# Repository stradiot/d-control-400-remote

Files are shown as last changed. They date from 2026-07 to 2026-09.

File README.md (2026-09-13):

# Dogtrace d-control 400 remote clone (ESP32-C3 + CC1101)

A small ESP32-C3 board that reproduces the *beep* command of a Dogtrace d-control 400 dog collar, making it triggerable from Home Assistant rather than only from the handheld remote.

The repository contains everything needed to build one: firmware for two runtimes (bare PlatformIO, and ESPHome for the Home Assistant path), a fabrication-ready PCB, a 3D printable enclosure, the SDR analysis script, and a written account of how the radio link was measured and decoded.

⚠️ **Scope and disclaimers**

* **Undocumented protocol.** Dogtrace publishes nothing about the link. Everything here was measured from SDR captures. The frame has since been decoded far enough to describe its structure — see [What the frame looks like](#-what-the-frame-looks-like) — but the firmware **does not use that decode**. It still replays a stored payload verbatim.
* **Raw replay, not synthesis.** The transmitted signal is a fixed-code payload captured with an SDR, cleaned up and re-emitted as raw timings, clocked onto the CC1101's GDO0 pin by the ESP32-C3's RMT peripheral in asynchronous direct mode: no packet engine, no sync word, no CRC. The encoding is **run-length** — all the information is in the durations and none in the levels. It is *not* PWM, despite what earlier revisions of this file claimed: PWM would need exactly half the runs long, and a real frame has 21 long runs out of 88.
* **Device specific.** The payload committed here was captured from one physical remote and is not a universal key for every d-control 400. The 68 runs that stay constant across everything that handset can send are *assumed* to be its identity — an assumption that has never been tested, because testing it needs a second remote. See [What the frame looks like](#-what-the-frame-looks-like). What this repository gives you is a structural template; you supply your own captured frame.
* **A fresh clone does not compile.** `include/signal.h` in this repository is encrypted, so it is not valid C. Replace it with your own capture using the template in [Providing your own signal](#-providing-your-own-signal).
* **Beep only.** The shock function is deliberately out of scope. As of the September 2026 decode that is a policy rather than a limitation: the frame is understood well enough to construct a shock command, and this repository deliberately does not carry what would be required to build one.
* **Legal.** 868 MHz is a licence-exempt band in Europe with duty-cycle limits, and transmitting on it is your responsibility. So is anything you do with a device that talks to an animal's collar.

---

## 📺 Demo

Demonstration of the project triggering the collar's sound beep function.

<div align="center">
  <video src="https://github.com/user-attachments/assets/95b2df5f-6e3d-44ce-ad21-af88bca1a0c2" controls="controls" style="max-width: 100%;">
  </video>
</div>

> **Note:** The video contains sound

---

## 📁 Repository Structure

```
.
├── src/main.cpp          # Standalone firmware — button, LED, TX sequence, serial console
├── include/              # Shared by the two firmware paths
│   ├── pinout.h          # Pin map for the custom SPI routing on the C3
│   ├── signal.h          # RF parameters + captured payload — ENCRYPTED, see below
│   ├── rmt_beep.h        # Transmission core — packs the frame, drives the RMT channel
│   ├── cc1101_config.h   # The six RadioLib calls that set the radio's RF personality
│   ├── led_policy.h      # Status LED palette, as levels emitted by the WS2812
│   └── reset_reason.h    # esp_reset_reason() as a printable string
├── esphome/              # Home Assistant path: d-control-400.yaml + cc1101.h
├── tools/analyze_capture.py  # IQ → envelope → run lengths → symbol period → frame → encoding tests
├── signal_captures.txt   # Decoded-frame worksheet — ENCRYPTED, not a build input
├── pcb/
│   ├── gerber.zip        # Fabrication-ready Gerbers
│   └── board-outline.dxf # Board outline, holes and pads in mm — for enclosure CAD
├── enclosure/            # Fusion 360 source + STEP + STL/3MF
├── doc/                  # Demo video, enclosure photos, PCB layer views
├── .githooks/            # Commit guard that keeps the two encrypted files encrypted
├── platformio.ini        # PlatformIO project/build configuration
└── README.md
```

`test/`, `lib/` and `include/README` are empty PlatformIO scaffolding. There are no tests.

The two encrypted files are the author's own captured data and are explained in [Encrypted files](#-encrypted-files-and-the-commit-guard). Nothing in the build reads `signal_captures.txt`.

---

## 🧰 Hardware Requirements

* **Microcontroller:** Wemos LOLIN C3 Mini (ESP32-C3, single-core RISC-V, USB-C).
* **Radio:** CC1101 transceiver module — must be the **868 MHz** variant with a **26 MHz** crystal. The 433 MHz part will not reach 869.525 MHz.
* **Antenna:** 868 MHz quarter-wave, roughly 8.2 cm.
* Optional: the PCB in `pcb/` and the printed enclosure in `enclosure/`. Hand-wiring on perfboard works just as well.

---

## 🔌 Wiring Diagram

The project uses a custom SPI bus routed to specific pins on the ESP32-C3. The physical BOOT button on GPIO 9 is used to trigger the transmission.

```mermaid
graph LR
    subgraph Wemos LOLIN C3 Mini
        3V3[3.3V Power]
        GND[Ground]
        G3[GPIO 3]
        G1[GPIO 1]
        G0[GPIO 0]
        G8[GPIO 8]
        G10[GPIO 10]
        G9[GPIO 9]
        G7[GPIO 7]
    end

    subgraph CC1101 Module
        VCC_C[VCC]
        GND_C[GND]
        MOSI[MOSI]
        SCK[SCK]
        MISO[MISO]
        GDO0[GDO0]
        CSN[CSN]
    end

    3V3 ---|Power| VCC_C
    GND ---|Ground| GND_C
    G3 ---|SPI MOSI| MOSI
    G1 ---|SPI SCK| SCK
    G0 ---|SPI MISO| MISO
    G8 ---|GDO0| GDO0
    G10 ---|SPI CS| CSN
    G9 ---|BOOT Button| BUTTON_PIN
    G7 ---|RGB LED| LED_PIN
```

Only **GDO0** is wired. Asynchronous direct mode maps that pin's logic level straight onto the power amplifier, so it is the entire data path; GDO2 is left unconnected.

---

## 🧩 PCB

A fabrication-ready two-layer board is included at `pcb/gerber.zip`. It routes the SPI bus and control pins between the LOLIN C3 Mini and the CC1101 module exactly as shown above. Upload the zip to any fab house (JLCPCB, PCBWay, OSH Park) as-is. It is optional — hand-wiring per the diagram is a fully valid alternative.

| Top | Bottom |
| :---: | :---: |
| PCB top layer | PCB bottom layer |

The dark rectangle sitting under the C3's antenna is the pour keepout, and it is visible on both views because it is cut through both layers. The bottom view is mirrored, as seen through the board.

`pcb/board-outline.dxf` carries the same geometry in millimetres — board outline, every drilled hole (24 plated, 4 mounting), pad positions and the module footprints, each on its own DXF layer. It is there so the mechanical side can be worked without opening an EDA tool: import it as a sketch in Fusion 360, FreeCAD or anything else that reads DXF, and build a case, a mounting plate or a panel cutout straight off the real dimensions.

**Layout**

* **Module placement.** The two modules sit at opposite ends of the board. The CC1101 is positioned so its antenna overhangs the board edge completely, with no substrate underneath to detune or absorb it. The C3 Mini is at the other end with its USB-C connector overhanging that edge, where the enclosure cutout reaches it — but its own antenna cannot be given the same treatment, because it falls close to the centre of the board, over laminate and copper pour. That is what the keepout below is for.
* **ESP antenna keepout.** A copper-pour keepout sits under the ESP32-C3's onboard antenna on **both** layers, so the antenna radiates through bare laminate rather than over a ground plane. It is a rectangle roughly 12 mm wide that extends about 3 mm past the end of the module, so the fringing field clears the pour as well as the antenna trace itself.
* **Mounting holes.** 2.032 mm at the corners, with the pour pulled back for clearance around the hardware.
* **Radio footprint.** The CC1101 header is 1×8 on a 2.00 mm pitch (`header-pin-1x8-2.00`), verified against the module.

**Routing**

* Power traces from the 3.3 V rail are 0.5 mm; signal traces are 0.254 mm.
* Ground pins tie into a full-coverage polygon pour through thermal reliefs, so the ground is solid but the pads still take a hand-soldering iron.
* DRC minimum track width was tuned to the design and the board passes cleanly.

**Ordering**

Fab defaults are fine for everything except board thickness: order **1.6 mm**, which is what the enclosure's standoffs are dimensioned for. The 0.5 mm power trace assumes 1 oz copper. Everything else — material, surface finish, mask colour — is free choice; the photographed board is black with leaded HASL because it was hand-assembled with leaded solder.

---

## 📡 CC1101 RF Configuration Summary

Only the carrier frequency comes from a datasheet. The rest were derived from SDR measurement and iterative testing against the collar.

| Parameter | Value | Why it matters |
| :--- | :--- | :--- |
| Carrier frequency | 869.525 MHz | The frequency the collar listens on. Confirmed on an SDR waterfall. |
| Output power | 10 dBm | Enough for whole-house range; see the note on chopping at range below. |
| Modulation | OOK | Confirmed on the waterfall — the carrier is simply gated on and off. |
| Bit rate | 100.0 kbps | Deliberate ~20× oversampling of a ~4.8 kBaud signal. Not a mistake — see below. |
| Rx bandwidth | 116.0 kHz | Selects a stable hardware filter tap off the 26 MHz crystal, on a transmit-only device. Not dead config. |
| Sync word | Disabled | Raw pulses; the packet engine is bypassed entirely. |
| Preamble / CRC | Disabled | Same reason — asynchronous direct mode. |
| Transmission mode | Asynchronous direct | GDO0's logic level maps straight to the PA. HIGH = RF on, LOW = RF off. |
| Symbol period | 208.647 µs | Measured, not estimated. Stored as 78 RMT channel ticks of 2.675 µs = 208.65 µs, +14 ppm. Every run is one or two of these. See [Measuring the symbol period](#measuring-the-symbol-period). |

---

## 🚀 Technical Specifics

### 1. 20× bitrate oversampling

A symbol period of 208.647 µs is a signalling rate of about 4.8 kBaud, yet the CC1101's data rate register is set to 100 kbps.

That is deliberate. In asynchronous mode the CC1101 samples the GDO0 pin on its own internal clock derived from that register. Set to 4.8 kbps it would look at the pin roughly once per symbol, and every edge would land wherever the two clocks happened to be relative to each other — visible as heavy jitter on the gating of the power amplifier. At 100 kbps it samples about every 10 µs, roughly 20 times per symbol, so each edge is reproduced to within a twentieth of a symbol. Do not "fix" this to match the real baud rate.

### 2. Receive bandwidth on a transmit-only device

`RX_BANDWIDTH` looks like dead configuration, and it is not. The CC1101 derives its channel filter from a chain of dividers off the 26 MHz crystal, and the register selects which tap. 116.0 kHz picks a tap that divides cleanly, which keeps the internal clock tree — and therefore the shape of the transmitted bursts — stable. In OOK the synthesiser stays parked at 869.525 MHz regardless.

### 3. Clocking the waveform out of hardware

The ESP32-C3 is a single-core RISC-V part running FreeRTOS, so a CPU-generated waveform is at the mercy of every other task: a preemption mid-frame stretches a run by however long the other task took. The firmware used to answer that with `vTaskSuspendAll()` around each burst. It worked, and it cost a great deal — the scheduler had to be released periodically or the task watchdog fired (a 159 ms burst followed by a 5 ms gap rebooted the ESPHome build with `ESP_RST_TASK_WDT`), and the release had to be brief or the beep audibly chopped.

The waveform is now clocked out by the **RMT** peripheral — Remote Control Transceiver, built for exactly this class of signal and already driving the WS2812 status LED. The 88-run frame is packed into the channel's own memory as 44 words of two level-plus-duration entries each, and the hardware loops it for as many frames as the beep needs. The CPU's entire involvement is one `rmt_transmit()` call that returns immediately; the transmission ends in an interrupt.

Three constraints disappear together: no scheduler suspension, no watchdog exposure, and no gap. A beep is one genuinely continuous transmission for its whole duration, which is what holding the original remote's button produces and what the bit-banged version could not do at all.

What replaces them is a shorter list of facts about the peripheral, all of which are properties of the RMT group rather than of this firmware:

* **The clock source and the prescale belong to the group, not the channel.** The first channel created fixes both for every later one. On this board that first channel is normally the status LED, which asks for `RMT_CLK_SRC_DEFAULT` — APB on the C3 — so the radio channel asks for APB explicitly rather than relying on init order. A mismatch is a hard `ESP_ERR_INVALID_ARG`, "group clock conflict", not a silent fallback. Both firmware paths therefore run the same divider of 214, a channel tick of exactly 2.675 µs, and emit a bit-identical waveform.
* **There are two TX-capable channels and 48 words of memory each.** The LED holds one, the radio the other, with nothing spare. Under ESPHome the LED must be pinned with `rmt_symbols: 48`, because the default on the C3 is 96 — two blocks — and a two-block channel claims its neighbour's, leaving the radio nowhere to go.
* **The C3 has no loop auto-stop.** `SOC_RMT_SUPPORT_TX_LOOP_COUNT` is defined, `SOC_RMT_SUPPORT_TX_LOOP_AUTO_STOP` is not, so reaching the frame count raises an interrupt and the driver stops the channel from its own ISR. A few entries can still reach the air after the target, which truncates the last frame rather than dropping it — the same thing the real remote does when the button is released. GDO0's resting level is forced from a register (`eot_level`, which the driver also writes to `RMT_IDLE_OUT_LV`) rather than taken from the end marker, so even an abort mid-frame leaves the pin low and the carrier off.

### 4. Contiguity — the property that decides whether it works at all

This is the single most important property of the transmission, and the least obvious.

**Frames are emitted back-to-back with no silence between them.** The original remote never inserts a gap mid-transmission: a tap is 7 contiguous frames (~159 ms) and a ~4.1 s hold is ~180 contiguous frames, with no OFF period longer than two symbol periods anywhere inside either. Verified across three captures and 13 presses.

This is not a detail. A firmware build that sent **one** frame followed by a 5 ms gap produced **zero** beeps, while an earlier, badly mistimed payload that happened to pack about 2.5 frames into each burst worked around 70% of the time. Two receiver behaviours explain it, and both demand contiguity:

* **Consecutive-frame validation** — cheap fixed-code decoders confirm a frame by requiring the next one to arrive and match before a timer expires. A gap expires that timer on every frame.
* **AGC settling** — a few milliseconds without carrier lets the receiver's gain drift toward the noise floor, corrupting the start of the next frame, which is exactly where the preamble lives.

Under RMT contiguity is free rather than bought, so the three layered knobs the bit-banged firmware needed — contiguous frames per burst, silence between bursts, number of bursts — collapse into one:

| Macro | Meaning | Bounded by |
| :--- | :--- | :--- |
| `BEEP_DURATION_MS` | How long the beep lasts | The RMT loop counter: ten bits, so 1023 frames — about 23 s — in one batch |

The other two are gone because nothing in the protocol ever wanted them. Both existed only because the CPU cannot hold `vTaskSuspendAll()` indefinitely, so a long transmission had to be chopped into pieces with scheduler windows between them; the gap in particular was a ceiling on damage (5 ms inaudible, 30 ms audibly chopping) rather than a value with a right answer. The evidence that the receiver never needed them was already in hand before the migration: with the gap set to zero at runtime on the standalone path, 126 frames ran back-to-back over 2.87 s — the shape of a real button hold — and decoded 6/6.

That the payload's run count is **even** is what makes the hardware loop legal, and it is a property of the frame rather than a convenience. Each RMT word holds two entries, so 88 runs is exactly 44 words with no half-filled tail; and because the frame starts ON and ends OFF, each repeat begins with a real OFF→ON edge instead of two same-level runs merging at the seam. The peripheral replays each entry's stored level bit verbatim and never enforces alternation, so an odd-length frame could not be looped out of a single block at all.

The wrap back to the first entry is **free**, which is worth knowing for anything else that loops RMT output. The reference manual says only that the transmitter "starts transmitting the first data again" and does not say whether the jump costs any output time; measured here, it costs none. Nine beeps from 22 to 1011 frames, each bracketed by `esp_timer_get_time()`, give a per-frame period matching the predicted 22,742.85 µs with a residual slope of −0.66 ns per frame against a ±2 ns bound — six times smaller than the 12.5 ns a single APB clock would add. A fixed +5 µs appears in every measurement and does not grow with frame count, which is what identifies it as software overhead at the two ends rather than anything the peripheral does.

The measurement is a **slope**, not an elapsed time, and that is the part worth copying. Neither timestamp is an edge: the first lands after the channel is enabled but before the first edge reaches the pin, the second after the interrupt, the vector and the driver's prologue. Those offsets are unknown but fixed, and a fixed offset added to one duration is indistinguishable from a fixed per-seam cost summed over that beep. Varying the frame count separates them — the offsets do not scale with it and a per-seam cost does — so the intercept absorbs the software and the slope is the hardware.

---

## 📻 What the frame looks like

Decoded in September 2026 from a differential capture campaign — beep and shock, channels A and B, all 20 shock levels, 42 distinct frames extracted from raw IQ and cross-checked against hand measurements in Universal Radio Hacker.

Every frame this handset sends is **88 runs** of one or two symbol periods (T = 208.647 µs), and the encoding is **run-length**: the levels carry no information at all, because two adjacent runs at the same level would merge into one. Everything is in the durations. That rules out NRZ, Manchester, PWM and PPM outright, and `periods = 88 + (number of long runs)` holds as an identity on every frame measured — 109 periods for a beep, 22.7 ms of air time.

The frame boundary is found on durations alone: a frame is the 88 runs beginning at the **last 31 unit runs before a double**. Anchoring instead on the start of the visible alternating stretch does not work, because that stretch is the preamble plus the tail of the previous frame and its length depends on the data.

Of the 88 runs, **68 are identical across everything the handset transmits** — both functions, both channels, all 20 intensity levels. The remaining 20 carry the whole command surface. Writing `A` for a short run and `B` for a long one:

```
run     field
0-30    preamble          31 short runs
31-44   constant          handset-specific
45-46   channel           AB = channel A,  BA = channel B
47-66   constant          handset-specific
67-68   function          AB = beep,       BA = shock
69-70   constant          handset-specific
71-78   level             8 runs, MSB first, long = 1
79-86   redundancy        run 79+i against run 71+i:
                            i = 0..3   always complement
                            i = 4,5    complement = shock, copy = beep
                            i = 6,7    (complement, copy) = channel A
                                       (copy, complement) = channel B
87      constant          always short
```

The redundancy block is the interesting part, and it is not a checksum. It is the level field re-emitted through a mask: four of its eight positions always invert the original, and the other four invert or copy depending on which channel and which function is being sent. Each command field is therefore stated twice — once outright in its own runs, and once as a perturbation of the redundancy. A receiver that validates the two halves against each other reads the command out of the comparison itself, which buys error detection and addressing from the same bits.

Neither the channel nor the function field ever uses `AA` or `BB` — only the two transposed values. That admits two readings the captures cannot separate, since there are only two observations of each field: either they are two-bit fields with two states spare, leaving room for two more functions and two more channels, or they are one-bit fields in a balanced 1-of-2 code where `AA` and `BB` are invalid codewords and there is no headroom at all. The d-control range includes models with more channels, so a higher model in the family would settle it.

The level field takes 20 distinct values across the 20 dial positions, read MSB first as an 8-bit number. That sequence is monotone and strongly non-linear, and no formula has been recovered from it. What the value *means* is unknown: nothing here establishes whether it is a physical quantity or simply an opaque index, and RF capture alone cannot say.

**What is published here and what is not.** The schema above is a property of the protocol, discoverable by anyone with this model and an SDR, so it is written down. The 68 constant runs and the level-to-value table are one specific handset's identity, and they are the only thing that makes a frame *this* remote's; those stay encrypted.

### The open question behind the "device specific" disclaimer

The 68 constant runs are *assumed* to be this handset's identity, and that assumption has never been tested. All that has been shown is that they are constant under every axis a single handset can vary, which is a much weaker claim. **Settling it requires a second remote** — nothing captured from this one will do it. Diffing two handsets splits the constant block into what differs (identity) and what agrees (protocol framing), with one confounder worth designing for in advance: two remotes may also differ by firmware revision, since each remote and collar ships as a pair. A third handset disambiguates, and so does the shape — an identifier is likely one contiguous field, a revision counter likely sits apart and takes small values.

---

## 🔑 Providing your own signal

`include/signal.h` holds both the RF parameters and the captured payload, and **the copy in this repository is encrypted**, so a fresh clone will not compile. To build the project you replace it with a header describing your own remote.

Capture the signal from the remote you want to clone with an SDR in AM/ASK mode, extract the run lengths, and write them into the file below.

The payload is stored as **run lengths in symbol periods**, not absolute microseconds. Every element is a whole number of `SYMBOL_TICKS` RMT channel ticks, so the entire frame is parameterised by that one number. Keep it that way — it is what allows the symbol period to be swept at runtime without re-deriving the payload.

```cpp
#pragma once

#define CARRIER_FREQUENCY 869.525 // Carrier frequency in MHz
#define OUTPUT_POWER 10           // CC1101 transmit power in dBm
#define BIT_RATE 100.0            // Async oversampling rate in kbps
#define RX_BANDWIDTH 116.0        // Receiver filter bandwidth in kHz

#define BEEP_DURATION_MS 3000     // How long the collar beeps. The firmware rounds this
                                  // to a whole number of frames and loads that into the
                                  // RMT loop counter, which tops out at 1023 (~23 s).

#define SYMBOL_TICKS 78           // Symbol period, in RMT channel ticks
#define RMT_RESOLUTION_HZ 373832  // Requested channel tick rate. The driver rounds to the
                                  // nearest integer divider -- 214 off an 80 MHz group
                                  // clock, a 2.675 us tick, so T = 78 x 2.675 = 208.65 us.

// Replace the numbers below with your captured run lengths, in symbol periods.
// Positive = RF ON (GDO0 HIGH), negative = RF OFF.
// Absolute duration of element i is T * abs(SIGNAL_BEEP_TICKS[i]).
#define SIGNAL_BEEP_TICKS { \
  1, -1, 2, -2, 1, -1, ... \
}
```

> **Note:** Keep every macro above. Both firmware paths require all of them and neither will compile without them.

Two properties of `SIGNAL_BEEP_TICKS` are checked at compile time, because the RMT cannot loop a frame that violates either:
>
> * **An even number of runs.** Each RMT word holds two entries, and the peripheral replays each entry's stored level bit verbatim rather than enforcing alternation, so an odd-length frame would put two same-level runs against each other at the loop seam and merge them.
> * **At most 94 runs.** That is 47 words, leaving room for the one word the driver appends as the end marker inside a 48-word channel block. Loop mode cannot refill the block as it plays, so the whole frame has to be resident.
>
> If your remote's frame is longer than 94 runs, the RMT path cannot loop it out of one block and the design needs revisiting rather than a bigger constant.

### Getting the numbers out of a capture

`tools/analyze_capture.py` takes the whole pipeline — IQ file to envelope to run lengths to symbol period to frame boundaries to encoding tests — and is the fastest way to a first answer. Given a `signal.h` it also works backwards, reading `SYMBOL_TICKS` and `RMT_RESOLUTION_HZ` to recover the timebase. Two things are worth doing anyway:

* **Measure a dozen short and long pulses by hand first**, and check the script against them rather than the other way round. The script was validated against synthetic captures with known ground truth before it was ever pointed at real data, and that caught three bugs in it, any one of which would otherwise have read as a property of the signal.
* **Capture several presses in one recording.** Cutting the result at the frame period and checking the copies are byte-identical costs nothing, needs no external ground truth, and catches errors in the crop, the sample rate, the symbol slot, the threshold and the frame boundary long before any of them are visible by eye.

One verdict the script prints deserves reading carefully. If runs cap at 2× and no standard encoding fits, it reports that the frame is most likely **run-length coded** — the levels carrying no information, which rules out NRZ, Manchester, PWM and PPM together — and names a clamped capture as the alternative. Those two look identical in its tables and are separated by one hand measurement, not by argument: check the runs against the tick grid, where a healthy run-length frame sits on-grid with a tight spread and a clamped one scatters rounding errors through the frame. That distinction cost a session here. The clamping reading fitted everything on screen and was wrong — 13 presses came out 0% off-grid at σ/mean 0.6%.

Two capture-side traps are worth naming, because both cost a session here:

* **Tune off-centre.** The RTL2832U places a DC spike at whatever frequency it is tuned to, so a carrier captured dead centre sits under an artefact that is not in the air. The 869.525 MHz signal was captured at 869.275 MHz — 250 kHz low.
* **Turn the gain down.** With the remote held close and the gain up, the waterfall showed three marks, not one: the real burst, its I/Q image mirrored about the tuned centre, and a third-order intermodulation product at roughly three times the baseband offset. The test that separates them is to retune and see what moves — real transmissions stay put on an absolute axis, images and distortion products follow your tuning. Use manual gain, not AGC, so nothing modulates the amplitudes you are trying to measure.

### Measuring the symbol period

Everything else falls out of the symbol period, so it is the one number to measure rather than estimate. **Take it frame-start to frame-start**: the rising edge that opens one frame against the rising edge that opens a frame several repeats later, divided by the number of symbol periods between them. Here that was 272 910 samples across exactly 654 periods at 2.000 MSps — 417.294 samples per period, or **208.647 µs**, with the six intermediate estimates agreeing to within 0.02%.

Two properties of that baseline are what make it trustworthy, and both are about the endpoints rather than the span:

* Both endpoints are **rising edges at the same structural position**, so rise-time bias is identical at each end and cancels instead of accumulating. Measuring edge-to-edge across a single pulse biases high by the rise and fall time.
* **The period count is known exactly.** A press ends when the button is released, which truncates the final frame at an arbitrary point, so the total period count of a whole message is not knowable and dividing by it is guesswork. Two frame starts sidestep that.

⚠️ Do not let a tool fit the symbol length for you. URH's *Autodetect parameters* reports 400 samples/symbol on this signal — wrong by 9%.

---

## 🔒 Encrypted files and the commit guard

Two files in this repository are encrypted with [SOPS](https://github.com/getsops/sops) and age:

| File | What it is |
| :--- | :--- |
| `include/signal.h` | RF parameters and the captured payload for the author's own remote |
| `signal_captures.txt` | The decoded-frame worksheet — the 68 constant runs and the level-to-value table |

This is a personal choice about the author's own captured data, not a build system. **You do not need SOPS, an age key, or any of this to use the project** — you need your own `signal.h`, written from the template above. `signal_captures.txt` is not a build input; nothing includes it.

What *does* affect anyone working in this repository is `.githooks/pre-commit`, which is committed. It refuses any commit that stages either file in plaintext, and warns when either is sitting decrypted in the working tree. It inspects the **staged blob** rather than the file on disk, and detects encryption by looking for SOPS's own markers, so it needs no key and works fine on a machine that cannot decrypt anything. Enable it with:

```bash
git config core.hooksPath .githooks
```

One wrinkle worth knowing if you have global hooks: a repository-local `core.hooksPath` **replaces** the global one rather than adding to it, so enabling the guard would silently stop your global hooks from running. `.githooks/prepare-commit-msg` exists to chain through to the global directory, with a re-entry guard — because a global hook that chains the other way resolves the repo's hook via `core.hooksPath`, lands back on the shim, and forks until the process table fills.

---

## 🛠️ Software Setup

Built with [PlatformIO](https://platformio.org/). Dependencies (RadioLib for the CC1101, Adafruit NeoPixel for the status LED) are pinned in `platformio.ini` and fetched automatically.

1. Write your own `include/signal.h` as described above.
2. Connect the LOLIN C3 Mini over USB.
3. Build and flash:

```bash
pio run                                      # build only
pio run --target upload                      # flash
pio run --target upload --target monitor     # flash and open the serial console at 115200
```

No port is configured in `platformio.ini`. The board declares USB VID/PID `303A:1001`, so PlatformIO finds it automatically; if several Espressif boards are attached, pass one explicitly:

```bash
pio run -t upload --upload-port /dev/cu.usbmodem101
```

On macOS prefer `/dev/cu.*` over `/dev/tty.*` — the latter blocks on open waiting for a carrier-detect signal that a USB CDC device never asserts.

---

## 🚥 Status Indication

The onboard RGB LED reports the device state:

* 🟢 **Green, 0.5 s once at boot:** CC1101 initialised successfully.
* 🟢 **Green pulse, 150 ms every 5 s:** liveness heartbeat — powered, running, radio OK.
* 🟠 **Amber pulse, 150 ms every 5 s** *(ESPHome path only)*: alive and radio OK, but **Wi-Fi is down**.
* 🔴 **Solid red, never pulsing:** radio initialisation failed — check the SPI wiring.
* 🔵 **Solid blue:** transmitting. The heartbeat is suppressed for the duration.
* ⚫ **Off:** no power, or the firmware has crashed.

The heartbeat exists so that idle is distinguishable from dead. On the ESPHome path its colour encodes the Wi-Fi state because nothing else can: a device with a dropped link is alive and transmits fine but is invisible to Home Assistant *and* to `esphome logs`, so the LED is the only witness — a plain green pulse there would be a false all-clear in exactly the failure mode where you walk over and look at the board. And a board sitting solid red and never pulsing has exactly one problem rather than two — by different means on each path. The ESPHome heartbeat carries an explicit radio-ready condition, because that path survives a failed init and would otherwise pulse green over a dead radio; the standalone path needs no condition, because a failed init halts in `setup()` and the heartbeat is never reached.

---

## 🎮 Usage

1. Power the board and check for the green flash — CC1101 initialised.
2. Confirm the green heartbeat every 5 seconds. That is the device reporting it is alive and idle.
3. Press the BOOT button. The LED turns blue for the transmission (~3 s), then returns to the heartbeat.

---

## 🎛️ Serial Console

The standalone firmware exposes its RF parameters over the serial monitor (115200 baud) so they can be changed without reflashing. Nothing is persisted — a reset restores whatever was compiled in from `signal.h`.

| Command | Effect |
| :--- | :--- |
| `k <ticks>` | Symbol period, in RMT channel ticks (`SYMBOL_TICKS`; 78 = 208.65 µs, one step is 1.28%) |
| `d <ms>` | Beep duration |
| `p <dBm>` | Output power |
| `f <MHz>` | Carrier frequency |
| `t` | Transmit one beep |
| `m` | Loop-seam sweep — nine beeps of increasing length, reported as `frames,us,cycles` for fitting |
| `?` | Print current state and the computed frame duration, frame count and beep length |

It exists so that a new capture can be brought in without a reflash between trials, which is the situation these parameters are actually uncertain in. The values committed here are already settled, so nothing needs sweeping on a working build.

When bringing up your own signal, the useful diagnostic is that the two common faults look different: a wrong symbol period produces *intermittent* triggering, a wrong frame structure produces *none at all*. If the collar never responds, check the payload and the run count before touching the timebase — no amount of sweeping will find that fault.

`k` and `d` are refused while a beep is in flight, and either is refused if the result would not fit the hardware: a symbol period whose long run overflows the RMT's 15-bit duration field, or a beep longer than one 1023-frame batch.

`m` is the instrument the loop-seam figure above came from, and it is about 90 seconds of continuous transmission — the collar beeps for all of it, so power it down or take it out of range first, and mind the duty cycle limit in the 869.4–869.65 MHz sub-band. It also prints a `cpu counter Hz` line, which is not decoration: it reports what the CPU's cycle counter is actually doing over the same span, so the measurement states its own reference rather than assuming it. On this part that number comes out near 159.6 MHz rather than the nominal 160, for the reason in the next section.

### A trap: `esp_cpu_get_cycle_count()` is not a clock on the C3

The first version of the seam instrument used the CPU cycle counter as its reference and produced a confident, reproducible, wrong answer — a per-frame period 2370 ppm *below* prediction, which is impossible, since a loop wrap can only add time.

The counter is the problem. `soc_caps.h` defines `SOC_CPU_HAS_CSR_PC` as 1 for this part, and `rv_utils_get_cycle_count()` branches on it:

```c
#if !SOC_CPU_HAS_CSR_PC
    return RV_READ_CSR(cycle);          /* the architectural counter */
#else
    return RV_READ_CSR(CSR_PCCR_MACHINE);   /* CSR 0x7e2 — a performance counter */
#endif
```

So what comes back is Espressif's performance counter, governed by `PCER` (which event) and `PCMR` (under what conditions) — an event counter, not a guaranteed tick of the CPU clock. Measured against the systimer it runs about **2370 ppm slow**, reproducibly, at roughly 159.62 MHz against a nominal 160. `getCpuFrequencyMhz()` will cheerfully report 160; it reports the *configured* frequency and says nothing about the counter.

Use `esp_timer_get_time()` for anything timing-critical. On the C3 its systimer has exactly one clock source — `clk_tree_defs.h` declares `SYSTIMER_CLK_SRC_XTAL` and nothing else — which is the same crystal the PLL behind the RMT's 80 MHz APB clock is locked to, so crystal error and drift cancel between the measurement and the thing being measured. It is also a free-running peripheral counter, so unlike a CPU counter it is indifferent to stalls, clock gating and CPU power state. At 1 µs granularity it resolves 0.04 ppm over a 23 s span.

---

## 🖨️ 3D Printed Enclosure

`enclosure/` contains parametric CAD and ready-to-print files for a case that houses the assembled board. The design prints without supports and uses a friction fit to hold the lid.

| Closed | Open |
| :---: | :---: |
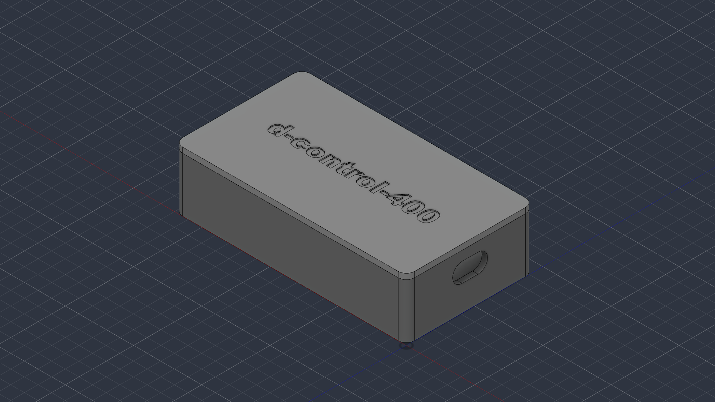
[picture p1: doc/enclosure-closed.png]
Enclosure closed
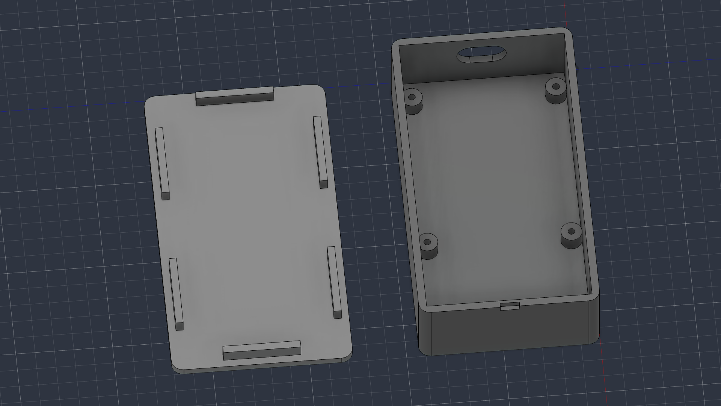
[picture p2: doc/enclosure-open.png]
Enclosure open showing the PCB inside
|  |  |

| File | Format | Purpose |
| :--- | :--- | :--- |
| `d-control-400-remote-enclosure.f3d` | F3D | Fusion 360 source, with full timeline and sketches |
| `d-control-400-remote-enclosure.step` | STEP | Universal CAD model, useful for collision checks in EDA software |
| `d-control-400-enclosure.3mf` | 3MF | PrusaSlicer project with orientation and print profiles preset |
| `d-control-400-case.stl` | STL | Case body mesh |
| `d-control-400-lid.stl` | STL | Lid mesh |

**Recommended print settings (Prusa MK4)**

* **Material:** PLA
* **Profile:** `0.20mm STRUCTURAL (Input Shaper)` — needed to hold the −0.1 mm friction-fit tolerance
* **Nozzle:** 0.4 mm
* **Supports:** none. The 13×7 mm USB-C cutout is sized so the printer bridges it cleanly
* **Orientation:** case flat on the plate; lid outer face (with the recessed text) on the plate for a smooth finish

The lid slides in until seated and is held by the interference fit. A hidden pry slot with an internal fillet sits on the top edge of the rear wall — insert a 5 mm flat-head screwdriver and lever the lid off.

---

## 🏠 ESPHome / Home Assistant

`esphome/` contains a complete ESPHome configuration that exposes the beep as a template switch, keeping the BOOT button working as a manual trigger. See [`esphome/README.md`](esphome/README.md) for setup; you will need to create `esphome/secrets.yaml` with your Wi-Fi credentials and an API encryption key.

```bash
cd esphome
esphome config d-control-400.yaml                              # validate
esphome run d-control-400.yaml                                 # compile + flash over USB
esphome run d-control-400.yaml --device d-control-400.local    # OTA
esphome logs d-control-400.yaml
```

Both firmware paths share everything in `include/` — the pin map, the payload and RF parameters, the transmission core, the radio's register configuration, the LED palette and the reset-reason decode — so a change to RF behaviour lands once rather than in both. What the two paths still own separately is the trigger surface, the LED mechanism and how each waits for the hardware to finish; those differences are deliberate and documented in `esphome/CLAUDE.md`.

Wi-Fi transmit power is capped at 8.5 dBm in the YAML. That is a hardware fix for LDO brownout on the C3 Mini's regulator, not a tuning preference — do not raise it.

> **Note:** the status LED can be exposed to Home Assistant by removing `internal: true` from the `status_led` component.

⚠️ Triggering an animal's collar from an automation without a physical confirmation step is a bad idea. The switch is there so a person can press it from a phone.

---

## 🧭 Possible future improvements

### Measure what a chained batch costs

The loop counter is ten bits, so a single batch tops out at 1023 frames — about 23 seconds. Past that the driver has to stop the channel and re-arm it, and that is a genuinely different seam from the loop wrap: the wrap is the peripheral reloading its own read pointer, which is measured above and costs nothing, whereas a chained batch is the CPU taking an interrupt and writing registers, so there is no reason to expect it to be free.

The firmware currently refuses to go there — `rmt_beep::set_duration_ms()` rejects any duration needing more than one batch — which is the right default while the cost is unknown, since contiguity is the one property the collar actually requires. Measuring it would mean lifting that limit behind a flag and running the same slope method across the boundary. Nothing here needs a beep longer than 23 seconds, so this buys knowledge rather than function.

---

## 📄 License

MIT — see [LICENSE](LICENSE). The software is provided "as is", without warranty of any kind. Use it responsibly and at your own risk, with the disclaimers at the top of this document in mind.

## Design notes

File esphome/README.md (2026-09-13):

# ESPHome / Home Assistant path

The Home Assistant half of the project. It exposes the collar's beep as a template switch, keeps the BOOT button working as a manual trigger, and shares its entire radio path with the standalone PlatformIO firmware in the repository root.

Start at the [root README](../README.md) for the hardware, the wiring, the PCB and the account of how the signal was measured and decoded. This file covers only what is specific to running the device under ESPHome.

---

## What is shared, and what is not

Both firmware paths include the same headers from `../include/`, so a change to RF behaviour lands once rather than twice:

```text
d-control-400-remote/
├── include/
│   ├── pinout.h          # Pin map
│   ├── signal.h          # RF parameters + captured payload — ENCRYPTED, supply your own
│   ├── rmt_beep.h        # Transmission core — packs the frame, drives the RMT channel
│   ├── cc1101_config.h   # The six RadioLib calls that set the radio's RF personality
│   ├── led_policy.h      # Status LED palette, as levels emitted by the WS2812
│   └── reset_reason.h    # esp_reset_reason() as a printable string
└── esphome/
    ├── d-control-400.yaml  # This configuration
    ├── cc1101.h            # cc1101_ctrl — radio init, and the two halves of a transmission
    └── secrets.yaml        # Wi-Fi credentials and API key — create this, it is gitignored
```

What the two paths still own separately is the trigger surface, the LED mechanism, and how each waits for the hardware to report it has finished. `led_policy.h` is the one shared header this path does *not* include — ESPHome's YAML cannot include a C header, so the YAML repeats those numbers as literals and cites the header. The reasoning is in `led_policy.h` itself.

---

## Setup

### 1. Create `secrets.yaml`

All three keys are required; `esphome config` fails without any one of them.

```yaml
wifi_ssid: "Your_SSID"
wifi_password: "Your_Password"
api_encryption_key: "base64-key-here"     # 32 random bytes, base64 — Home Assistant shows it when adding the device
```

### 2. Supply your own `include/signal.h`

The committed copy is encrypted and is not valid C, so a fresh clone will not compile. Write your own from the template in the [root README](../README.md#-providing-your-own-signal).

### 3. Build and flash

```bash
esphome config d-control-400.yaml                              # validate, no hardware needed
esphome run d-control-400.yaml                                 # compile + flash over USB
esphome run d-control-400.yaml --device d-control-400.local    # OTA
esphome logs d-control-400.yaml
```

---

## Status LED

| Indication | Meaning |
| :--- | :--- |
| 🔴 Solid red | Booting, or CC1101 initialisation failed |
| 🟢 Green flash at boot | Wi-Fi connected and radio ready |
| 🟢 Green pulse, 150 ms every 5 s | Alive, radio OK, Wi-Fi up |
| 🟠 Amber pulse, 150 ms every 5 s | Alive, radio OK, **Wi-Fi down** |
| 🔵 Solid blue | Transmitting (~3 s); the heartbeat is suppressed |

The amber state is the one worth knowing about. A device whose Wi-Fi has dropped is alive and transmits fine from the button, but it is invisible to Home Assistant *and* to `esphome logs` — so the LED is the only witness to that failure, and a plain green pulse there would be a false all-clear in exactly the case where you walk over and look at the board.

The heartbeat carries a radio-ready condition, so a board sitting solid red and never pulsing has exactly one problem (radio init) rather than two.

> The LED is `internal: true`. Remove that to expose it to Home Assistant.

---

## Implementation notes

**The waveform is clocked by hardware, not by the CPU.** `cc1101_ctrl::begin_transmission()` puts the radio into asynchronous direct mode and hands the frame to the ESP32-C3's RMT peripheral, then returns — in about 5 ms, most of it the synthesiser settle. The RMT clocks the whole beep out of its own memory and raises an interrupt at the end. There is no timing-critical section, no `vTaskSuspendAll()`, and no watchdog exposure; an earlier bit-banged version had all three, and reset the device with `ESP_RST_TASK_WDT`. `end_transmission()` returns the radio to standby afterwards and runs in task context, because it is SPI work and cannot happen inside the completion interrupt.

**Retriggering is ignore-while-busy.** A press or a switch toggle arriving mid-beep is dropped, not queued and not restarted: the device emits one precise beep per trigger and deliberately does not reproduce the original remote's press-and-hold behaviour. The script is `mode: single` and `rmt_beep::start()` refuses independently, so the Home Assistant switch and the physical button cannot race each other.

**`rmt_symbols: 48` on the LED is mandatory.** ESPHome defaults it to 96 on the C3, which is two of the RMT's 48-word memory blocks, and a two-block channel claims its neighbour's. The C3 has exactly two TX-capable channels — the LED holds one and the radio the other — so at the default the LED consumes both and the radio has nowhere to go.

**`gamma_correct: 1.0` on the LED is deliberate**, and every brightness percentage in the YAML depends on it. ESPHome's default of 2.8 applies brightness linearly to the 8-bit channel before the gamma lookup, which crushes the bottom of the range: the Wi-Fi-down pulse emitted `(1, 0, 0)` — pure red at one count out of 255, green quantised away — so amber was never actually on screen. The curve exists to smooth a dimming sweep; this LED shows three fixed colours and never sweeps.

**Wi-Fi power is capped at 8.5 dBm.** That is a hardware fix for LDO brownout on the C3 Mini's regulator, not a tuning preference. Do not raise it.

**RadioLib is pinned exactly**, matching `platformio.ini`. It sits directly in the transmit path, so a silent minor bump is a silent change to RF behaviour — and the two paths are only comparable if they build against the same version.

**Transmission is gated on `cc1101_ctrl::is_ready()`.** If the CC1101 does not answer on SPI at boot, the flag stays false and every trigger silently no-ops, which is what prevents an SPI crash on absent hardware. Keep any new trigger path behind it.

⚠️ Triggering an animal's collar from an automation without a physical confirmation step is a bad idea. The switch exists so that a person can press it from a phone.

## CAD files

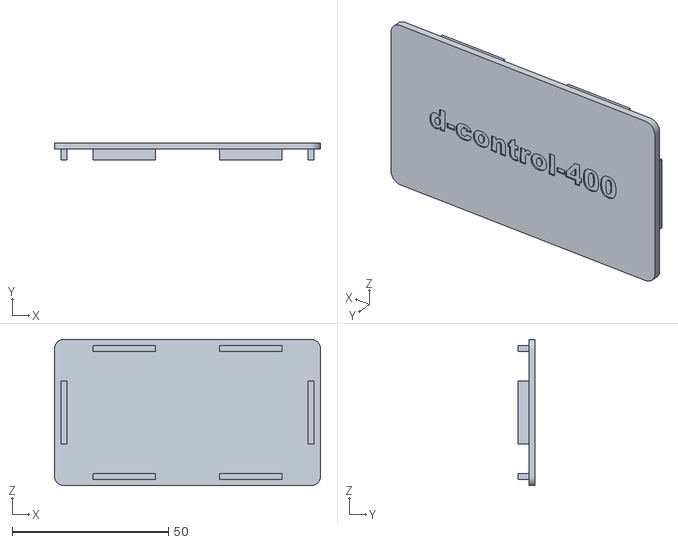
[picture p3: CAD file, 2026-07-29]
enclosure/d-control-400-lid.stl
85.0 x 5.50 x 46.7

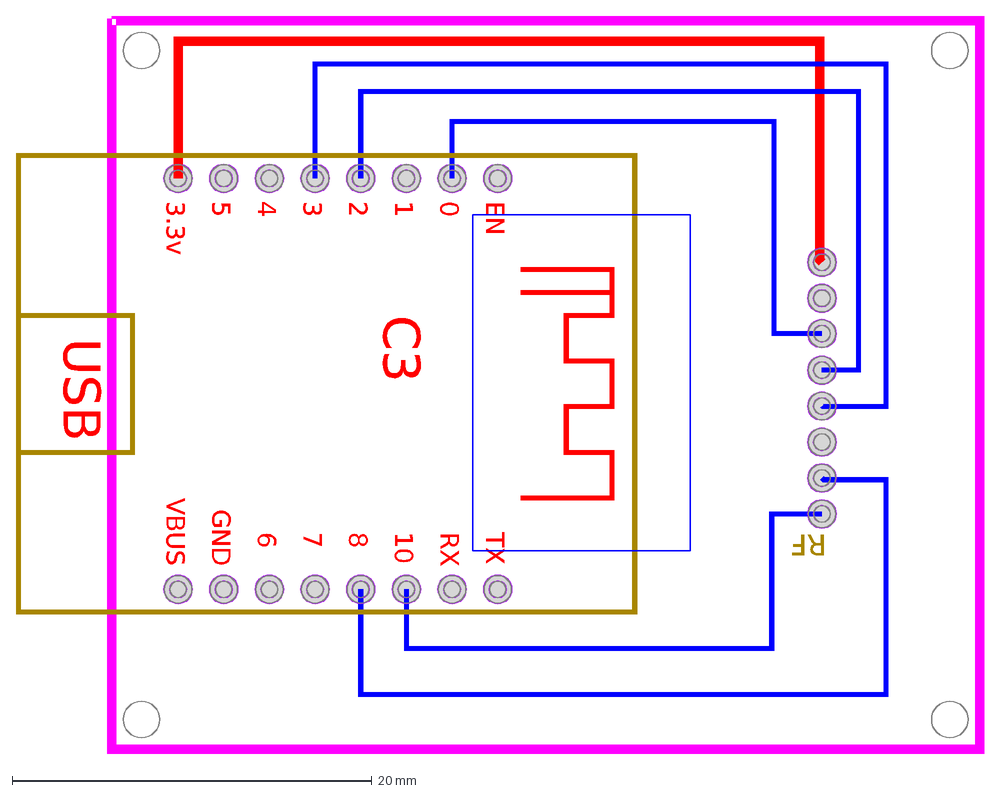
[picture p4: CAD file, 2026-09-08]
pcb/board-outline.dxf
RF
USB
C3
EN
GND
0
1
2
3
4
5
3.3v
TX
RX
10
8
7
6
VBUS

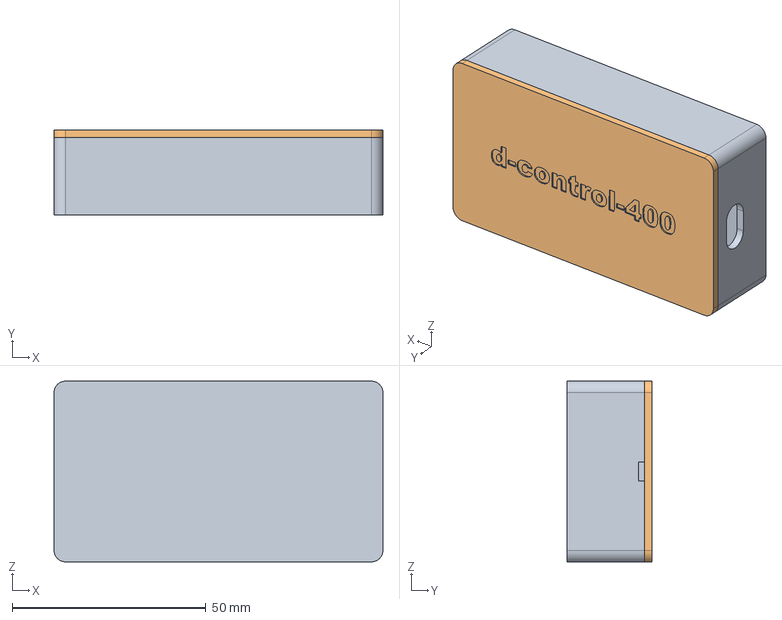
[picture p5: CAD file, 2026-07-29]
enclosure/d-control-400-remote-enclosure.step
85.0 x 22.0 x 46.7 mm

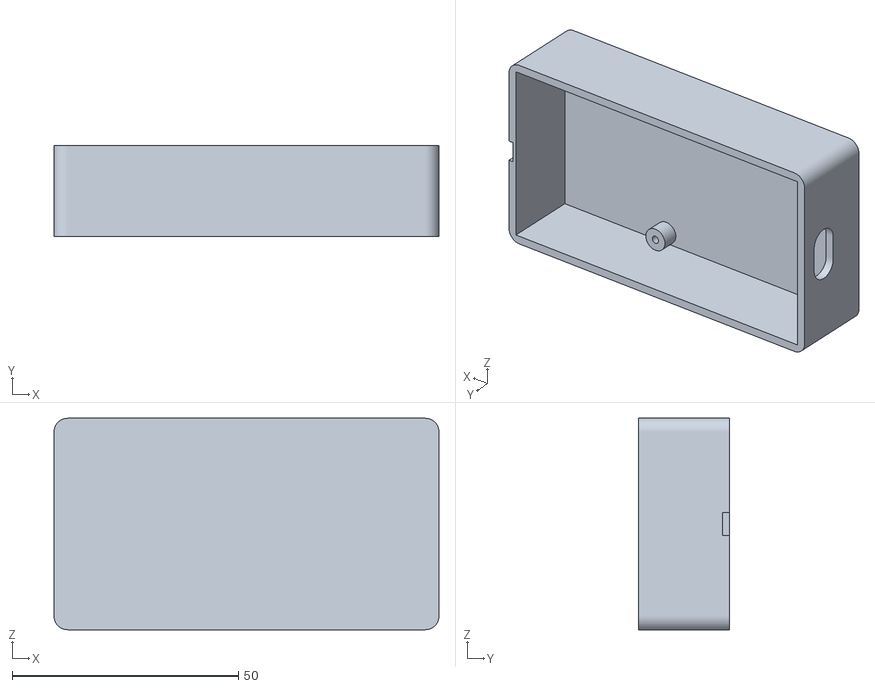
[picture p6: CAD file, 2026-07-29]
enclosure/d-control-400-case.stl
85.0 x 20.0 x 46.7

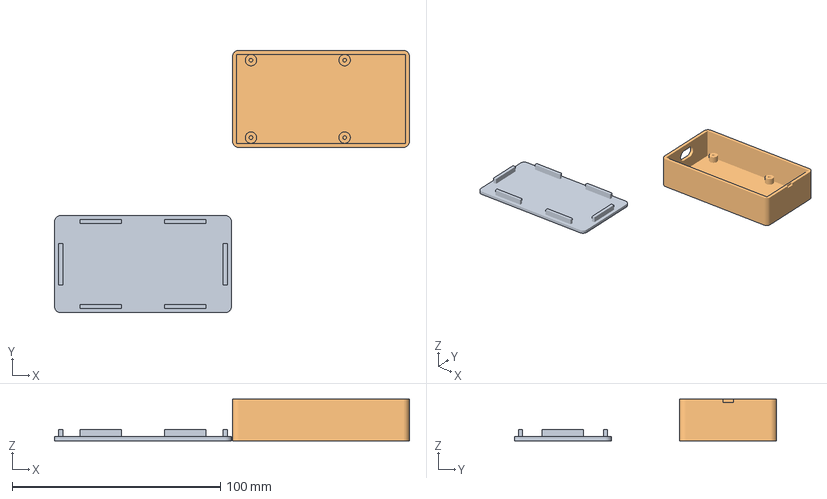
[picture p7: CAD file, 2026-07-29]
enclosure/d-control-400-enclosure.3mf
170.5 x 126.1 x 20.0 mm
d-control-400-lid.stl
d-control-400-case.stl

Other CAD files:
enclosure/d-control-400-remote-enclosure.f3d

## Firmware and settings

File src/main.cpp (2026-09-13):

#include <Arduino.h>
#include <RadioLib.h>
#include <SPI.h>
#include <Adafruit_NeoPixel.h>

#include "signal.h"
#include "pinout.h"
#include "led_policy.h"
#include "cc1101_config.h"
#include "reset_reason.h"
#include "rmt_beep.h"

SPIClass customSPI(FSPI);
// RADIOLIB_NC for the GPIO argument: GDO0 belongs to the RMT peripheral, and
// RadioLib must never drive or reconfigure it. The CC1101 side of the pin is set up
// by transmitDirect() over SPI, which is a register write and needs no MCU pin.
CC1101 radio = new Module(CC1101_CS, RADIOLIB_NC, RADIOLIB_NC, RADIOLIB_NC, customSPI);
Adafruit_NeoPixel strip(NUMPIXELS, LED_PIN, NEO_GRB + NEO_KHZ800);

// --- Runtime calibration parameters ---
// Seeded from signal.h, mutable over serial so a parameter sweep does not
// require a reflash per trial. Nothing is persisted; a reset restores defaults.
// The symbol period and the beep length live in rmt_beep.
int8_t outputPower = OUTPUT_POWER;
float carrierMHz = CARRIER_FREQUENCY;

// True between handing a beep to the RMT and putting the radio back in standby.
// The transmission itself runs in hardware, so loop() keeps running throughout.
bool txActive = false;

// --- Button Interrupt ---
volatile bool buttonTriggered = false;
unsigned long lastDebounceTime = 0;
constexpr unsigned long debounceDelay = 200;

// --- Liveness heartbeat ---
// An idle device used to be dark, which is indistinguishable from one that is
// dead or unpowered. A brief green pulse every HEARTBEAT_PERIOD_MS makes "alive
// and radio OK" visible at a glance. Short and dim on purpose: this repeats
// forever, so it must not be a nuisance in a room.
// Levels come from include/led_policy.h and are written to the strip verbatim --
// see the setBrightness(255) note in setup(). Adafruit applies no gamma curve and
// the ESPHome path now disables its own, so an emitted level means the same light
// on both paths and the two can be compared on the bench.
constexpr unsigned long HEARTBEAT_PERIOD_MS = LED_PULSE_PERIOD_MS;
constexpr unsigned long HEARTBEAT_ON_MS = LED_PULSE_MS;
constexpr uint8_t HEARTBEAT_GREEN = LED_LEVEL_PULSE;
unsigned long lastHeartbeatMs = 0;
bool heartbeatLit = false;

// --- Serial command buffer ---
char cmdBuf[32];
uint8_t cmdLen = 0;

// --- Loop-seam sweep ---
// Instrumentation for what the RMT's loop wrap costs. Answered 2026-09-13 -- nothing,
// to within +/-2 ns per frame, where one APB clock would be 12.5 ns -- and kept for
// the same reason the k sweep is kept: it is how the achieved channel clock gets
// checked at runtime instead of inferred. See the header comment on
// rmt_beep::tx_start_us for why this must be read as a slope.
//
// Both timestamps sit a fixed, unknown number of cycles away from the first and last
// edges, and a fixed offset added to one elapsed time is indistinguishable from a
// fixed per-seam cost summed over that beep -- same sign, same magnitude, same on
// every press. The frame count is the lever that separates them: the offsets do not
// scale with it and the seam does. Fit elapsed time against frames; the intercept absorbs
// every fixed cost and the slope is the per-frame period the hardware actually
// realises, wrap included.
//
// Durations, not frame counts, because set_duration_ms() is the existing knob;
// frame_count() rounds each to whole frames and last_frame_count() reports what it
// landed on. The points do not need to be round numbers, only known ones. The span
// runs from ~22 frames to just under the 1023-frame batch ceiling, which is the
// widest lever arm available without chaining a second batch.
constexpr uint32_t SWEEP_MS[] = {500, 1000, 2000, 4000, 8000, 12000, 16000, 20000, 23000};
constexpr size_t SWEEP_STEPS = sizeof(SWEEP_MS) / sizeof(SWEEP_MS[0]);
constexpr unsigned long SWEEP_GAP_MS = 2000;

bool sweepActive = false;
bool sweepPending = false;  // a beep is in flight and not yet harvested
size_t sweepStep = 0;
unsigned long sweepNextMs = 0;
uint32_t sweepSavedMs = 0;
uint32_t sweepFrames[SWEEP_STEPS];
int64_t sweepUs[SWEEP_STEPS];
uint32_t sweepCycles[SWEEP_STEPS];

// Serial.print() has no 64-bit overload, and casting to int32_t silently wrapped the
// first sweep's 3.59e9-cycle span to a negative number. Everything wide goes through
// here instead.
void printI64(int64_t v) {
    char buf[24];
    snprintf(buf, sizeof(buf), "%lld", (long long)v);
    Serial.print(buf);
}

//
// --- LED Feedback ---
void setLEDColor(uint8_t r, uint8_t g, uint8_t b) {
    strip.setPixelColor(LED_INDEX, strip.Color(r, g, b));
    strip.show();
}

void clearLED() {
    strip.clear();
    strip.show();
}

// Non-blocking two-state pulse driven from loop(). Deliberately not a delay():
// loop() has to stay responsive to the button flag and to serial commands.
//
// The txActive guard is required, and it was not before the RMT migration. The old
// transmit call blocked loop() for the whole sequence, so the heartbeat and the
// transmission were mutually exclusive by construction. Now the beep runs in
// hardware while loop() keeps turning, so both ends of the pulse have to stand
// aside: starting one would overwrite the blue, and clearing one that began just
// before the trigger would blank the LED for the whole beep.
//
// Period is measured pulse-start to pulse-start; lastHeartbeatMs is only
// advanced when the LED lights. Unsigned arithmetic makes it millis()-rollover
// safe, same as the debounce above.
void pollHeartbeat() {
    if (txActive) {
        return;
    }

    unsigned long now = millis();

    if (!heartbeatLit) {
        if (now - lastHeartbeatMs >= HEARTBEAT_PERIOD_MS) {
            setLEDColor(0, HEARTBEAT_GREEN, 0);
            heartbeatLit = true;
            lastHeartbeatMs = now;
        }
    } else if (now - lastHeartbeatMs >= HEARTBEAT_ON_MS) {
        clearLED();
        heartbeatLit = false;
    }
}

// --- Interrupt Service Routine ---
void IRAM_ATTR handleButton() {
    unsigned long currentTime = millis();
    if (currentTime - lastDebounceTime > debounceDelay) {
        buttonTriggered = true;
        lastDebounceTime = currentTime;
    }
}

// Hands one beep to the RMT and returns. A press arriving while a beep is already
// on the air is ignored, not queued: the device emits one precise beep per press.
bool startTransmit() {
    if (txActive || rmt_beep::is_busy()) {
        Serial.println(F("busy - trigger ignored"));
        return false;
    }

    setLEDColor(0, 0, LED_LEVEL_SOLID); // Blue

    int state = radio.transmitDirect(); // Enter transparent mode
    if (state != RADIOLIB_ERR_NONE) {
        Serial.print(F("ERR transmitDirect failed, code: "));
        Serial.println(state);
        setLEDColor(LED_LEVEL_SOLID, 0, 0);
        delay(500);
        clearLED();
        return false;
    }

    delay(5); // Let the frequency synthesiser settle before the first edge

    if (!rmt_beep::start()) {
        Serial.println(F("ERR rmt_beep::start failed"));
        radio.standby();
        setLEDColor(LED_LEVEL_SOLID, 0, 0);
        delay(500);
        clearLED();
        return false;
    }

    txActive = true;
    return true;
}

// Called from loop(). The RMT clears its busy flag from the loop-end interrupt;
// putting the radio back to standby is SPI work and has to happen in task context.
void pollTransmit() {
    if (!txActive || rmt_beep::is_busy()) {
        return;
    }

    int state = radio.standby();
    if (state != RADIOLIB_ERR_NONE) {
        Serial.print(F("ERR standby failed, code: "));
        Serial.println(state);
    }

    txActive = false;
    clearLED();

    // Restart the heartbeat cycle rather than letting a pulse fire the instant the
    // beep ends: the beep outlasts HEARTBEAT_PERIOD_MS, so the timer is always
    // overdue by the time the transmission finishes.
    heartbeatLit = false;
    lastHeartbeatMs = millis();

    Serial.println(F("TX done"));

    // One measurement point per beep, whether it came from the sweep, a button or a
    // 't'. Raw cycles and the frame count the loop counter was actually given --
    // deliberately not a derived period, because a single point cannot give one.
    Serial.print(F("MEAS frames=")); Serial.print(rmt_beep::last_frame_count());
    Serial.print(F(" us=")); printI64(rmt_beep::last_tx_us());
    Serial.print(F(" cycles=")); Serial.println(rmt_beep::last_tx_cycles());
}

// The frame period the hardware is predicted to realise, in NANOSECONDS, derived at
// runtime rather than hardcoded so a wrong clock shows up as a wrong prediction
// instead of a silent assumption. The divider is what the driver picked for the
// requested resolution (214 off an 80 MHz APB). Nanoseconds because the exact value
// is 22742.85 us -- an integer number of nanoseconds, and not an integer number of
// microseconds, so this is the coarsest unit that stays exact: 8502 x 214 x 12.5.
uint64_t predictedNsPerFrame() {
    const uint32_t apbHz = getApbFrequency();
    const uint32_t divider = (apbHz + RMT_RESOLUTION_HZ / 2) / RMT_RESOLUTION_HZ;
    return (uint64_t)rmt_beep::frame_channel_ticks() * divider * 1000000000ULL / apbHz;
}

// Prints the sweep as raw triples, for fitting off-device. The endpoint slope below
// is a sanity check and NOT the result: two points cannot show whether the relation
// is linear, and non-linearity would mean one of the "fixed" offsets is not fixed.
void printSweepResult() {
    const uint64_t predictedNs = predictedNsPerFrame();

    Serial.println(F("--- loop-seam sweep ---"));
    Serial.print(F("  apb Hz            : ")); Serial.println(getApbFrequency());
    Serial.print(F("  channel ticks/frm : ")); Serial.println(rmt_beep::frame_channel_ticks());
    Serial.print(F("  predicted ns/frm  : ")); printI64((int64_t)predictedNs); Serial.println();
    Serial.println(F("  frames,us,cycles"));

    for (size_t i = 0; i < SWEEP_STEPS; ++i) {
        Serial.print(F("  ")); Serial.print(sweepFrames[i]);
        Serial.print(F(",")); printI64(sweepUs[i]);
        Serial.print(F(",")); Serial.println(sweepCycles[i]);
    }

    const int64_t df = (int64_t)sweepFrames[SWEEP_STEPS - 1] - (int64_t)sweepFrames[0];
    const int64_t dus = sweepUs[SWEEP_STEPS - 1] - sweepUs[0];
    const int64_t dcyc = (int64_t)sweepCycles[SWEEP_STEPS - 1] - (int64_t)sweepCycles[0];
    if (df > 0 && dus > 0) {
        // Excess per frame in nanoseconds. One channel tick is 2675 ns, so whole-tick
        // and even sub-tick wrap costs are both readable here without floating point.
        const int64_t excessNs = (dus * 1000 - (int64_t)predictedNs * df) / df;
        Serial.print(F("  endpoint dframes  : ")); printI64(df); Serial.println();
        Serial.print(F("  endpoint dus      : ")); printI64(dus); Serial.println();
        Serial.print(F("  excess ns/frm     : ")); printI64(excessNs); Serial.println();
        // The diagnostic: what the CPU performance counter's rate actually is over the
        // same span. It is not 160 MHz, and this line is the evidence rather than an
        // assumption -- see the note in rmt_beep.h.
        Serial.print(F("  cpu counter Hz    : "));
        printI64(dcyc * 1000000LL / dus); Serial.println();
    }
}

// Non-blocking sweep driver, stepped from loop(). One beep per point, harvested
// after the ISR has cleared busy and the radio is back in standby, then a gap before
// the next -- the gap is not a settling requirement, it just keeps a 23 s burst from
// running straight into the next one.
void pollSweep() {
    if (!sweepActive || txActive || rmt_beep::is_busy()) {
        return;
    }

    if (sweepPending) {
        sweepFrames[sweepStep] = rmt_beep::last_frame_count();
        sweepUs[sweepStep] = rmt_beep::last_tx_us();
        sweepCycles[sweepStep] = rmt_beep::last_tx_cycles();
        sweepPending = false;
        sweepStep++;
        sweepNextMs = millis() + SWEEP_GAP_MS;
        return;
    }

    if ((long)(millis() - sweepNextMs) < 0) {
        return;
    }

    if (sweepStep == SWEEP_STEPS) {
        sweepActive = false;
        rmt_beep::set_duration_ms(sweepSavedMs);
        printSweepResult();
        return;
    }

    if (!rmt_beep::set_duration_ms(SWEEP_MS[sweepStep]) || !startTransmit()) {
        Serial.println(F("ERR sweep aborted"));
        sweepActive = false;
        rmt_beep::set_duration_ms(sweepSavedMs);
        return;
    }
    sweepPending = true;
}

// --- Serial calibration interface ---
void printState() {
    Serial.println(F("--- calibration state ---"));
    Serial.print(F("  k  symbol ticks   : ")); Serial.print(rmt_beep::symbol_ticks);
    Serial.print(F(" (")); Serial.print(rmt_beep::symbol_period_ns());
    Serial.println(F(" ns)"));
    Serial.print(F("  d  beep ms        : ")); Serial.println(rmt_beep::beep_duration_ms);
    Serial.print(F("  p  power dBm      : ")); Serial.println(outputPower);
    Serial.print(F("  f  carrier MHz    : ")); Serial.println(carrierMHz, 3);
    Serial.print(F("     runs per frame : ")); Serial.println(rmt_beep::kRunCount);
    Serial.print(F("     frame us       : ")); Serial.println(rmt_beep::frame_duration_us());
    Serial.print(F("     frames         : ")); Serial.println(rmt_beep::frame_count());
    Serial.print(F("     actual beep us : ")); Serial.println(rmt_beep::beep_duration_actual_us());
    Serial.println(F("  t  transmit once     ?  this help"));
    Serial.println(F("  m  loop-seam sweep (~90 s of airtime -- silence the collar)"));
}

void executeCommand(const char *cmd) {
    const char *arg = cmd + 1;
    while (*arg == ' ') arg++;

    switch (cmd[0]) {
        case 'k': {
            // Symbol period sweep, in RMT channel ticks per symbol. One step is
            // 1/SYMBOL_TICKS of the period, about 1.28% at the default of 78.
            uint32_t v = strtoul(arg, nullptr, 10);
            if (!rmt_beep::set_symbol_ticks(v)) {
                Serial.println(F("ERR k rejected (busy, or period/frame count out of range)"));
                break;
            }
            Serial.print(F("OK symbol = ")); Serial.print(rmt_beep::symbol_period_ns());
            Serial.print(F(" ns, frame = ")); Serial.print(rmt_beep::frame_duration_us());
            Serial.print(F(" us, frames = ")); Serial.println(rmt_beep::frame_count());
            break;
        }
        case 'd': {
            uint32_t v = strtoul(arg, nullptr, 10);
            if (!rmt_beep::set_duration_ms(v)) {
                Serial.println(F("ERR d rejected (busy, or over 1023 frames in one batch)"));
                break;
            }
            Serial.print(F("OK beep = ")); Serial.print(rmt_beep::beep_duration_ms);
            Serial.print(F(" ms, frames = ")); Serial.print(rmt_beep::frame_count());
            Serial.print(F(", actual = ")); Serial.print(rmt_beep::beep_duration_actual_us());
            Serial.println(F(" us"));
            break;
        }
        case 'p': {
            int v = atoi(arg);
            int state = radio.setOutputPower(v);
            if (state != RADIOLIB_ERR_NONE) {
                Serial.print(F("ERR setOutputPower code: ")); Serial.println(state);
                break;
            }
            outputPower = (int8_t)v;
            Serial.print(F("OK power = ")); Serial.println(outputPower);
            break;
        }
        case 'f': {
            float v = atof(arg);
            int state = radio.setFrequency(v);
            if (state != RADIOLIB_ERR_NONE) {
                Serial.print(F("ERR setFrequency code: ")); Serial.println(state);
                break;
            }
            carrierMHz = v;
            Serial.print(F("OK carrier = ")); Serial.println(carrierMHz, 3);
            break;
        }
        case 't':
            if (startTransmit()) {
                Serial.println(F("TX ..."));
            }
            break;
        case 'm':
            // Loop-seam sweep. Long and loud: roughly 87 s of airtime plus gaps, and
            // the collar beeps for every second of it. Power the collar down or take
            // it out of range first, and mind the duty cycle in the 869.4-869.65 MHz
            // sub-band.
            if (sweepActive || txActive || rmt_beep::is_busy()) {
                Serial.println(F("ERR m rejected (busy)"));
                break;
            }
            sweepSavedMs = rmt_beep::beep_duration_ms;
            sweepStep = 0;
            sweepPending = false;
            sweepNextMs = millis();
            sweepActive = true;
            Serial.print(F("sweep started, ")); Serial.print(SWEEP_STEPS);
            Serial.println(F(" points"));
            break;
        case '?':
            printState();
            break;
        default:
            Serial.print(F("ERR unknown command '")); Serial.print(cmd[0]);
            Serial.println(F("' - send ? for help"));
            break;
    }
}

void pollSerial() {
    while (Serial.available()) {
        char c = (char)Serial.read();
        if (c == '\r') {
            continue;
        }
        if (c == '\n') {
            cmdBuf[cmdLen] = '\0';
            if (cmdLen > 0) {
                executeCommand(cmdBuf);
            }
            cmdLen = 0;
        } else if (cmdLen < sizeof(cmdBuf) - 1) {
            cmdBuf[cmdLen++] = c;
        }
    }
}

void setup() {
    Serial.begin(115200);
    delay(2000); // Give serial monitor time to connect

    // Why the chip last reset. Shared with the ESPHome path -- a brownout and a
    // watchdog reset are indistinguishable from outside the board and have
    // opposite fixes. This is the development path, so it gets the diagnostic too.
    Serial.print(F("last reset reason: "));
    Serial.println(reset_reason::describe());

    // 1. Initialize RGB LED
    strip.begin();
    // 255 disables Adafruit's global scaling entirely rather than setting it to
    // maximum: setBrightness() stores b + 1 in a uint8_t, so 255 rolls over to 0,
    // and show() skips the scaling pass when the stored value is 0. Colour
    // components are then written literally, which is what lets led_policy.h state
    // emitted levels instead of a level and a scale that have to be multiplied out.
    strip.setBrightness(255);
    clearLED();

    // 2. Configure Button and attach Interrupt
    pinMode(BUTTON_PIN, INPUT_PULLUP);
    attachInterrupt(digitalPinToInterrupt(BUTTON_PIN), handleButton, FALLING);

    // 3. Radio Initialization
    customSPI.begin(CC1101_SCK, CC1101_MISO, CC1101_MOSI, CC1101_CS);

    int state = radio.begin();
    if (state == RADIOLIB_ERR_NONE) {
        Serial.println(F("CC1101 radio initialized successfully!"));
        // Flash Green to indicate radio is ready
        setLEDColor(0, LED_LEVEL_SOLID, 0); // Green

        delay(500);

        clearLED();
    } else {
        Serial.print(F("CC1101 radio initialization failed, code: "));
        Serial.println(state);
        // Flash Red if radio fails to initialize
        setLEDColor(LED_LEVEL_SOLID, 0, 0); // Red

        while (true);
    }

    // 4. Configure CC1101 settings for Dogtrace. Shared with the ESPHome path --
    // see include/cc1101_config.h. The runtime carrier and power are passed in
    // rather than defaulted, so a reset restores the captured values but a sweep
    // set over serial survives a re-apply.
    bool ok = cc1101_config::apply(radio, carrierMHz, outputPower);

    if (!ok) {
        Serial.println(F("CC1101 parameter configuration FAILED - readings will be unreliable"));
        setLEDColor(LED_LEVEL_SOLID, 0, 0); // Red
        while (true);
    }

    // 5. Claim GDO0 for the RMT. Deliberately after strip.begin(): the LED is the
    // other RMT client and both channels must agree on the group clock. Either
    // order works because both ask for APB, and this one makes the shared-clock
    // dependency visible rather than accidental.
    esp_err_t err = rmt_beep::init();
    if (err != ESP_OK) {
        Serial.print(F("RMT init FAILED, esp_err: ")); Serial.println(err);
        setLEDColor(LED_LEVEL_SOLID, 0, 0); // Red
        while (true);
    }

    Serial.println(F("System Ready. Press BOOT button or send 't' to transmit."));
    printState();
}

void loop() {
    pollSerial();

    if (buttonTriggered) {
        buttonTriggered = false; // Reset the flag before acting, so a press during
                                 // the beep is dropped rather than deferred.
        Serial.println(F("Button pressed! Transmitting..."));
        startTransmit();
    }

    pollTransmit();
    pollSweep();  // after pollTransmit: it harvests the point txActive has just freed
    pollHeartbeat();
}

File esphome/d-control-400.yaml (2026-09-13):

# ======================================================================
# CORE ESPHOME CONFIGURATION
# ======================================================================
esphome:
  name: d-control-400
  includes:
    - cc1101.h
    - ../include/pinout.h
    - ../include/signal.h
    - ../include/cc1101_config.h
    - ../include/reset_reason.h
    - ../include/rmt_beep.h
  libraries:
    - SPI
    # Pinned exactly rather than with a caret, for the same reason platformio.ini
    # pins it: RadioLib sits directly in the transmit path (transmitDirect, standby,
    # the CC1101 register writes), so a silent minor bump is a silent change to RF
    # behaviour -- and the two firmware paths are only comparable if they build
    # against the same one.
    - jgromes/RadioLib@6.6.0
  on_boot:
    # Priority 600 runs early in the boot sequence, before Wi-Fi connects
    priority: 600
    then:
      # 0. Report why the chip last reset (see the log_reset_reason script).
      #    on_boot runs before Wi-Fi is up, so this line only ever lands on the
      #    USB serial console; the api on_client_connected trigger below repeats
      #    it for the network log, which is where it actually gets read.
      - script.execute: log_reset_reason
      # 1. Immediately turn the LED Solid Red to indicate boot-up
      - light.turn_on:
          id: status_led
          brightness: 20%
          red: 1.0
          green: 0.0
          blue: 0.0
      # 2. Run the custom C++ CC1101 initialization routine
      - lambda: |-
          if (!cc1101_ctrl::setup()) {
            ESP_LOGE("cc1101", "CC1101 initialization failed!");
          }

esp32:
  board: lolin_c3_mini
  framework:
    type: arduino

# Enable standard Home Assistant API and over-the-air updates
api:
  encryption:
    key: !secret api_encryption_key
  # Repeat the reset reason whenever a client attaches, so `esphome logs` sees it
  # even though it connects long after on_boot has run. esp_reset_reason() reads a
  # latched RTC register, so it stays valid for the whole boot and can be re-read.
  on_client_connected:
    - script.execute: log_reset_reason
logger:
ota:
  - platform: esphome

# ======================================================================
# NETWORK CONFIGURATION
# ======================================================================
wifi:
  ssid: !secret wifi_ssid
  password: !secret wifi_password

  # CRITICAL HARDWARE FIX: Clamp the Wi-Fi transmit power to prevent
  # a voltage brownout on the ESP32-C3's tiny voltage regulator.
  output_power: 8.5dBm

  on_connect:
    - if:
        # Check the C++ flag to see if the CC1101 initialized properly
        condition:
            lambda: 'return cc1101_ctrl::is_ready();'
        then:
          # SUCCESS: Both Wi-Fi and Radio are good! Flash Green, then turn off.
          - light.turn_on:
              id: status_led
              brightness: 20%
              red: 0.0
              green: 1.0
              blue: 0.0
          - delay: 500ms
          - light.turn_off: status_led
        else:
          # HARDWARE FAILURE: Radio failed to init. Lock the LED to Solid Red.
          - light.turn_on:
              id: status_led
              brightness: 20%
              red: 1.0
              green: 0.0
              blue: 0.0

# ======================================================================
# HARDWARE COMPONENTS
# ======================================================================
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

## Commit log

2026-03-27 impr: code optimization
    - Move CC1101 logic to cc1101_ctrl namespace for better encapsulation
    - Replace Home Assistant button with script and momentary switch for beep trigger
    - Add LED utility functions and constants for improved feedback
    - Update signal.h encryption
    - Minor code cleanups and refactoring
    [d-control-400.yaml, main.cpp]
2026-04-13 feat(rf): switch to OOK modulation, update docs and config for OOK, remove FSK settings
2026-04-18 fix(pinout): update CC1101 pin assignments for better perfboard wiring
2026-04-23 docs(readme): update wiring diagram and pin assignments for Wemos LOLIN C3 Mini and CC1101 module
2026-04-24 feat(pcb): add gerber.zip for PCB fabrication
2026-07-20 feat(enclosure): add 3D printable case and lid models
    [d-control-400-case.stl, d-control-400-enclosure.3mf, d-control-400-lid.stl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]
2026-07-20 docs(readme): document enclosure, PCB, license and fix signal template
    - Add 3D printed enclosure section (files, print settings, assembly)
    - Add detailed PCB section (layout, routing/DRC, fab parameters)
    - Add repository structure map and MIT LICENSE
    - Fix signal.h template: include required TRANSMIT_REPEAT/TRANSMIT_GAP_US
    - Document repeated transmission, output power, and encrypted-clone note
    - Trim redundant status prose and fix typos
2026-07-21 feat(enclosure): update case, lid and CAD models
    [d-control-400-case.stl, d-control-400-enclosure.3mf, d-control-400-lid.stl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]
2026-07-29 feat(enclosure): redesigned lid lip for better friction and fit, shortened standoff to better fit the usb-c cutout
    [d-control-400-case.stl, d-control-400-enclosure.3mf, d-control-400-lid.stl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]
2026-07-29 docs(enclosure): add enclosure closed/open images and update README
2026-08-11 fix(rf): emit contiguous frame bursts instead of one frame per gap
    The collar decodes a frame only when the next one follows immediately.
    The original remote never inserts silence inside a transmission: a tap is
    7 contiguous frames (159.3 ms) and a 4.14 s hold is 180, with no OFF run
    longer than 2 ticks anywhere inside either. Verified against three
    RTL-SDR captures covering 13 presses.
    Firmware that sent one frame followed by a 5 ms gap produced no beeps at
    all, while the older mistimed payload that happened to carry 2.5 frames
    per burst worked ~70% of the time. The historic 70% was never a timing
    problem, it was burst structure.
    - add FRAMES_PER_BURST (7), emitted back-to-back inside one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
    [d-control-400.yaml, main.cpp]
2026-08-11 docs: burst contiguity, measured symbol period, watchdog constraint
    Several statements in the old docs were actively wrong and would have
    sent the next reader down the wrong path:
    - the gap was described as giving the receiver "a clear idle period to
    detect the start of each new burst". It does the opposite; a gap
    between frames stops the collar decoding entirely.
    - the symbol period was given as ~200 us "cleaned to the nearest 50-100
    us". It is 208.875 us, measured across 13 presses, and every run in
    every capture lands on that grid.
    - the watchdog was described as a non-issue because the sequence fits
    inside 5 s. It is a live constraint and did reset the device.
    Also adds a TOD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
2026-08-11 chore(tools): add analyze_capture.py, ignore .DS_Store and __pycache__
    IQ capture to envelope, run lengths, base tick, frame segmentation and
    line-coding tests in one script. Validated against two synthetic captures
    with known ground truth before being trusted on real data.
2026-08-11 docs: correct the symbol period to 208.647 us, add RMT and shock TODOs
    The previously documented 208.875 us (417.75 samples) came from a span of
    42 preamble ticks. Re-measured frame-start to frame-start -- 272910
    samples across exactly 654 ticks -- gives 417.294 samples = 208.647 us,
    with the six intermediate estimates agreeing to within 0.02%.
    That baseline is 16x longer, so its endpoint error is 16x smaller, and
    both endpoints are rising edges at the same structural position so
    rise-time bias cancels instead of accumulating. It also sidesteps the
    ambiguity in dividing the whole message span by its tick count: the final
    ON tick is truncated when the button is released, leaving no way to te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
2026-08-13 feat(led): pulse a liveness heartbeat, with Wi-Fi state in its colour
    An idle device was dark, which is indistinguishable from one that is dead
    or unpowered. Both firmware paths now emit a brief pulse every 5 s: short
    (80 ms) and dim (15%) because unlike the one-off boot flash this repeats
    forever and must not be a nuisance in a room.
    On the ESPHome path the colour carries the Wi-Fi state, which is the point
    rather than a flourish. A device whose Wi-Fi has dropped is alive and
    transmits fine but is invisible to Home Assistant *and* to `esphome logs`,
    so the LED is the only witness to that failure and a plain green pulse
    would be a false all-clear exactly when you walk over to look at it. Am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
    [d-control-400.yaml, main.cpp]
2026-08-15 build(pio): pin the platform, drop dead flags and hardcoded ports
    `platform = espressif32` resolved to whatever was installed locally -- here the
    pioarduino fork at 55.03.39 (Arduino core 3.3.9 / IDF 5.5.4). On a fresh clone
    that bare name resolves from the official PlatformIO registry instead, which
    stalled at 6.x with Arduino core 2.x / IDF 4.4. That would silently build the
    transmit loop against a different compiler and a different FreeRTOS, which is
    not a difference worth discovering in the field on firmware whose correctness
    is microsecond timing. Pinned by release URL.
    Dropped build_flags entirely: the lolin_c3_mini board definition already
    supplies -DARDUINO_USB_MODE=1 and -DARDUINO_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
2026-08-15 fix(rf): default the standalone path to the deadline timing engine
    First hardware run of this firmware -- it had compiled since 2026-08-11 but had
    never been flashed, so it carried three sessions of unexercised RF changes.
    Flashed over USB and tested against the collar, stationary at short range.
    timingMode defaulted to 0 (legacy), the engine that reproduces the ORIGINAL
    firmware bit-for-bit and that has never been validated against the collar. The
    ESPHome path implements only the deadline engine. Beyond the timing difference,
    mode 0 also skips the delay(5) synthesiser settle after transmitDirect(), so
    its opening edges go out before the CC1101's PLL has locked.
    Measured 6/6 clean on mode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
    [main.cpp]
2026-09-06 feat(protocol): decode the frame, and guard the secrets at commit time
    The differential capture campaign is closed. Beep and shock, channels A and B,
    all 20 shock levels: 42 distinct frames pulled straight from the IQ captures and
    known-answer checked against the thirteen hand-cut URH transcriptions that
    already existed, which they reproduce character for character.
    Every frame is 88 runs of one or two symbol periods, run-length coded. The levels
    carry nothing -- two adjacent runs at the same level would merge into one, so the
    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
2026-09-08 feat(pcb): refresh the gerber, add the DXF outline and layer views
    Re-export from EasyEDA 6.5.57. The board outline and all 28 drill
    positions are byte-identical to the previous export; what changed is a
    stray top-layer pour void under the middle of the C3 module, now gone,
    plus some rerouting on the bottom layer. The antenna keepout at
    X 32.9-45.0 is unchanged and cut through both copper layers.
    board-outline.dxf is the same geometry in millimetres, with the outline,
    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
    [board-outline.dxf]
2026-09-08 docs: drop the use-case framing from the README intro
    The beep was described as a recall signal, which is wrong -- it is a
    prohibitive command, and a README aimed at a stranger has no reason to
    carry either version. The project is the Home Assistant integration of
    the beep trigger; what the beep is used for is not its concern.
    Also drops the "by an automation, or from a phone" gloss, which sat
    awkwardly against the warning further down about triggering an animal's
    collar unattended. That nuance now lives only in the ESPHome section.
    Claude-Session: https://claude.ai/code/session_012j1ohjawJwYDphR4XcGUNo
2026-09-08 docs: cut the README's diary, and fix the PCB placement and ordering notes
    Module placement was wrong: only the CC1101's antenna overhangs an edge.
    The C3 Mini's own antenna sits close to the centre of the board, over
    laminate and pour, and what overhangs at that end is the USB-C
    connector. That is also the reason the keepout exists, so the two
    bullets now read together instead of contradicting each other.
    Replaced the manufacturing table with one ordering note. None of it was
    recoverable from the files -- gerbers carry geometry only, and grepping
    the set for material, thickness, finish or copper weight returns
    nothing -- so all four rows were fab order-form settings describing one
    person's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
2026-09-10 docs: correct the RMT capacity figure and close the TX-looping question
    The "88 runs = 44 symbols against a 48-symbol channel block" line double-counted:
    a symbol and a word are the same object in the RMT RAM, so the frame is 44 words
    against a 48-word block, and the block holds 96 pulses. The figure had never been
    read out of the reference manual.
    Chapter 33 also settles the open question underneath it — the C3 does have
    hardware TX looping, capped at 1023 iterations per batch, so continuous output
    does not necessarily need a wrap-around refill interrupt. What is still open is
    how to build a contiguous burst from it.
    Claude-Session: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
2026-09-12 feat: clock the transmission out of the RMT peripheral
    The OOK envelope is no longer bit-banged from the CPU under
    vTaskSuspendAll(). The 88-run frame is packed into an RMT channel's own
    memory as 44 words of two pulse codes, and the hardware loops it for the
    whole beep. rmt_transmit() queues and returns; the transmission ends in
    an interrupt.
    Three constraints go together, because all three descended from the CPU
    generating the waveform: no scheduler suspension, no watchdog exposure,
    and no gap. FRAMES_PER_BURST, TRANSMIT_GAP_US and TRANSMIT_REPEAT
    collapse into BEEP_DURATION_MS, which rounds to 132 frames of 22.743 ms
    for the loop counter. BASE_TICK_US 209 (+1692 ppm) becomes SYMBOL_TICKS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
    [d-control-400.yaml, main.cpp, rmt_beep.h]
2026-09-13 docs: stop justifying the platformio.ini pins in bit-banged terms
    Both comments argued from a timing-critical transmit loop that no longer
    exists. The platform pin's real justification turns out to be stronger than
    the one it carried: rmt_beep.h is written against the IDF 5.x RMT driver
    (driver/rmt_tx.h, rmt_new_tx_channel), and the registry's espressif32 6.x
    line is Arduino core 2.x / IDF 4.4, which ships only the legacy
    driver/rmt.h. A bare `espressif32` cannot compile this firmware at all --
    it fails, rather than silently building against a different FreeRTOS.
    The -O note claimed an optimisation change would move digitalWrite/micros
    inlining inside the timing-critical section. There is n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
2026-09-13 fix: unify the radio config, the LED palette and gamma across both paths
    First hardware validation of the RMT transmission: both firmware paths, the
    collar beeping, 6/6 on the standalone path with 3.002 s transmit windows
    against a predicted 3.00206 s, and a busy rejection that neither queued nor
    extended the beep. Everything below is what that bring-up turned up.
    Shared, where a divergence could not be seen without a range test:
    - include/cc1101_config.h holds the six RadioLib calls that were duplicated
    verbatim in src/main.cpp and esphome/cc1101.h. Carrier and power are
    parameters defaulting to signal.h, so the standalone serial sweep works.
    - include/reset_reason.h turns esp_reset_re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
    [d-control-400.yaml, led_policy.h, main.cpp]
2026-09-13 docs: record the RMT path as validated on hardware
    The TODO still said nothing had been on the air. Both paths are flashed and
    the collar beeps: 6/6 on the standalone path, transmit windows of 3.002 s
    against a predicted 3.00206 s, and a mid-beep press dropped without
    queueing or extending.
    Also notes what the bring-up actually proved -- reaching `System Ready`
    proves rmt_beep::init() returned ESP_OK, since both init failures halt
    behind a red LED, and the measured window pins the achieved clock at
    runtime rather than by inference.
    And warns off printState() as the reference for the seam measurement that
    remains: frame_duration_us() truncates to whole microseconds and
    beep_duration_actual_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
2026-09-13 docs: bring the README and the ESPHome guide up to today's code
    The README still listed include/ as two headers and claimed the paths share
    only pinout.h and signal.h, so "a change to RF behaviour usually has to land
    in both" -- which stopped being true when cc1101_config.h, reset_reason.h and
    led_policy.h joined rmt_beep.h there. The heartbeat is 150 ms, not 80.
    esphome/CLAUDE.md gains the three shared headers, and two implementation
    notes that are only obvious once you know the history:
    - There is deliberately no yield before begin_transmission(). One was needed
    when the bit-banged transmit held the main loop, because ESPHome's light
    component writes the LED from a loop pass; it is a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
2026-09-13 feat(rmt): timestamp transmissions and sweep the loop seam
    Adds the instrument that answers the one open question about the RMT
    migration: whether the peripheral's jump back to the first entry costs any
    output time. It does not — the per-frame period matches the predicted
    22742.85 us with a residual slope of -0.66 ns/frame against a +/-2 ns
    bound, where a single APB clock would be 12.5 ns.
    rmt_beep.h records esp_timer_get_time() and the CPU cycle count at both
    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
2026-09-13 fix: guard pinout.h, and pin RadioLib exactly on the ESPHome path
    Two latent problems found in a full review of the repository.
    pinout.h was the only header without #pragma once, and it is included
    twice on both paths: src/main.cpp then rmt_beep.h on one, cc1101.h then
    rmt_beep.h on the other. It compiles today only because the file contains
    nothing but object-like macros with identical replacement lists, which is
    a legal redefinition. The first const, enum or inline added there would
    break both builds at once.
    The ESPHome path asked for RadioLib ^6.0.0 while platformio.ini pins 6.6.0
    exactly, with a comment explaining that RadioLib sits directly in the
    transmit path so a silent minor bump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
    [d-control-400.yaml]
2026-09-13 docs: record the seam result, and correct what the review found stale
    The loop-seam measurement is written up in both READMEs and CLAUDE.md: the
    wrap is free, how the slope method separates it from fixed software
    offsets, and the esp_cpu_get_cycle_count() trap that defeated the first
    attempt. The root README's "possible future improvements" now names the
    batch-chaining seam instead, which is a different mechanism -- the CPU
    stopping and re-arming the channel rather than the peripheral reloading its
    read pointer -- and remains unmeasured.
    The rest is a sweep for claims that outlived the code they described:
    - esphome/README.md still described the bit-banged design, "a custom C++
    loop that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
2026-09-13 fix(tools): stop analyze_capture.py giving a confidently wrong answer
    Two defects, found by running the script against the repository's own
    committed payload rather than reading it.
    It could not read the current signal.h at all, and did not say so. The
    --header mode looked for BASE_TICK_US, which the RMT migration deleted, and
    on not finding it silently fell back to a 1 us base tick -- so a 22742.85 us
    frame was reported as "total duration 109 us" and every downstream number
    was wrong by the symbol period with nothing on screen to indicate it. It now
    reads SYMBOL_TICKS and RMT_RESOLUTION_HZ, derives the symbol period the way
    the firmware does (nearest whole divider off the 80 MHz APB clock,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
